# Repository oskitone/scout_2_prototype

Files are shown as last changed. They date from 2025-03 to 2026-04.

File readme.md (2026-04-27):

# scout_2_prototype

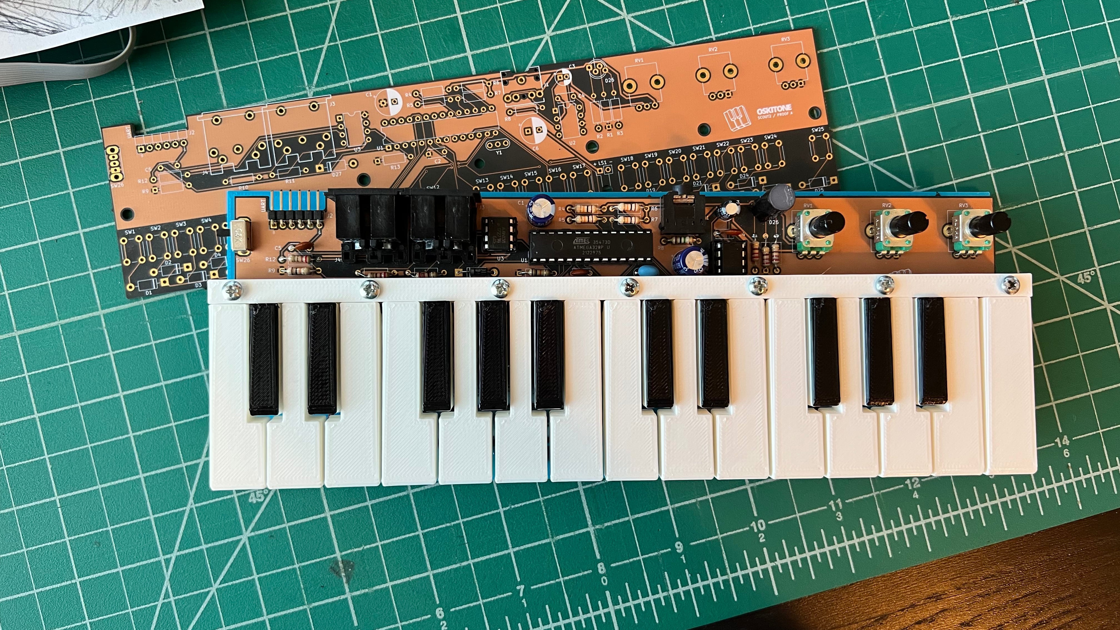
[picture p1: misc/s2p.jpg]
scout_2_prototype


This is a prototype around a PCB I sent off to fab in March 2022... that I'm slowly bringing back to life. I'm kind of using it as a springboard for the next thing, whatever that is and whenever it happens!

Very much work-in-progress. License will be MIT like other kits.

Forked from scout's [2-25_keys](https://github.com/oskitone/scout/tree/2-25_keys) branch

## In this repo

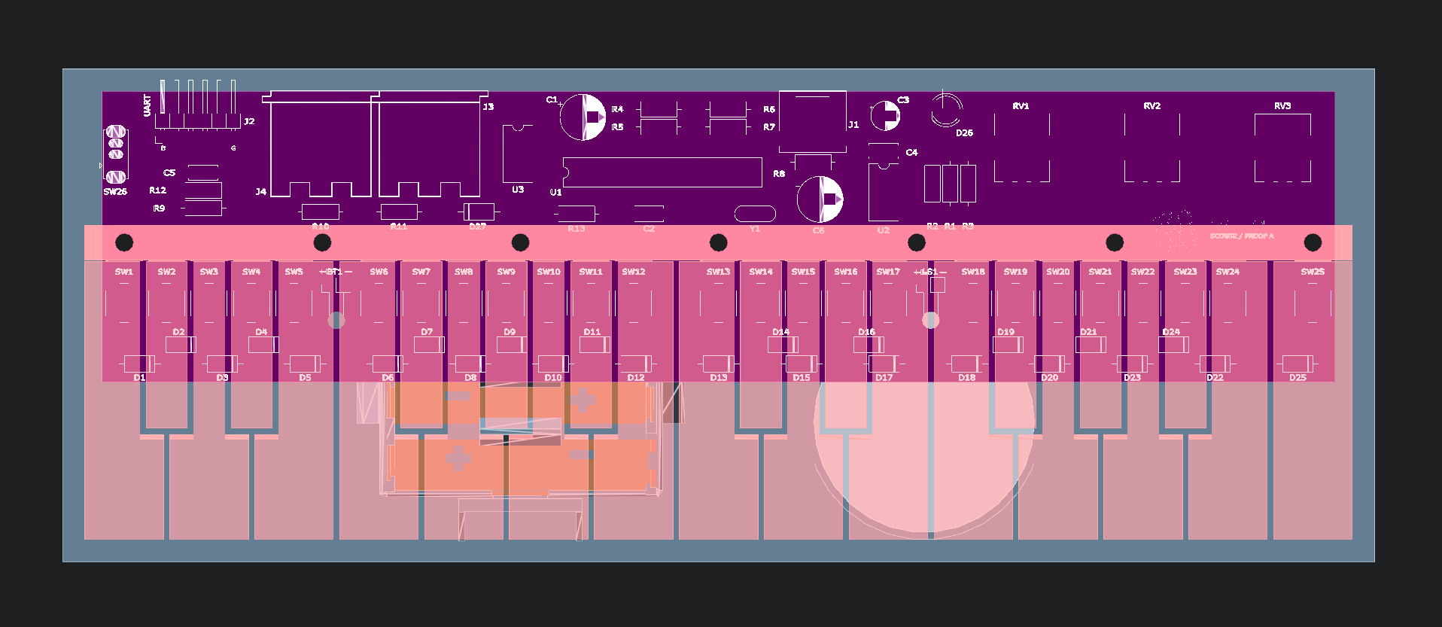
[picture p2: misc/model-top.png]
top view


- Kicad project
- OpenSCAD for scaffolding and keys models
- STLs for 3D-printing

## Goals

### Overarching Oskitone design goals

- Easy to solder. Only through-hole parts, even if it limits functionality.
- Easy to change. Code can be edited with free software and cheap hardware.
- Easy to play. No hidden menus, secret key combos, or overloading. One control per one function.
- Easy to understand. Code should be relatively accessible to anybody familiar with Arduino.
- Easy to hack. Programming header (TODO? hmm), usual open source ethos stuff.

### And specific to the next ~synth

- Polyphony
  - Per my ability, four is a reasonable number of notes to play simultaneously. Three is okay but would be frustrating. Two would be funny?
  - Anyway, four notes is what D9-12 are attempting. At the time, I was thinking I could tack some math around millis() and make the square waves manually... maybe use an interrupt timer? My pin choice seems random, and there're probably better choices.
- Any kind of musical connectivity
  - MIDI
    - USB is modern but circular DIN connectors are standard and inarguably answer the question "But can it do MIDI?!"
    - I think I'd also need non-DIP chips to do USB MIDI so that's out
    - I don't know if both IN and OUT are necessary or which to prefer if there can only be one. DIN connectors are big; [TRS MIDI](https://minimidi.world/) is an option.
  - Control Voltage
    - I'm open to this but don't really know the scene well enough to know what would be good. If it's easy to add, sure.
- Support for Mozzi w/o shipping w/ it
  - I want it to still feel solidly like an Oskitone instrument, for better and no doubt worse. Blame ["not invented here" syndrome](https://en.wikipedia.org/wiki/Not_invented_here).
  - Mozzi is cool as hell but it does require reading docs, which maybe breaks the "easy to understand" goal.
  - <del>Plus, even if I wanted to, I don't think Mozzi's license would permit me selling kits w/ it.</del> [Looks like they're GNU LGPL now](https://github.com/sensorium/Mozzi/pull/240), so may be okay.
  - That having been said, I want to engender "side-loading" things like this and make swapping to Mozzi straightforward, especially if the barrier to entry is low. So minimally it needs the right pins, an output filter, maybe other changes too.
- More musically useful than the Scout
  - Same size keys but as many as I can fit on a Prusa.
  - A semblance of control with analog input pots. Currently doing octave and glide.
  - Glide is fun but will be weird if/when polyphony is introduced. Could do poly only at 0 glide

## TODO / known issues / things for next rev

- 3D prints
  - Octave control really needs detents or some kinda tactile feedback on rotation.
- For next rev
  - More key mounting screw holes? Key bed subassembly with multiple parts
  - Rethink headphone output in signal path to minimize amplified noise
  - 386 bass boost?
  - Fix PROOF silkscreen text on back
  - Try shift register for 8 outputs? To resistor array!
  - Ditch MIDI in. Keep MIDI out but use TRS for smaller footprint
  - See if speaker can fit in new space?
- Tiny speaker is quick to distort and has no low end
- Make it clear/explicit how FUNCTION_INDICATOR_LED is used as "hanging" indicator. Right now, it's incidental.

Anything else?

https://github.com/user-attachments/assets/99f4f9d2-c58f-4821-b225-9032d2b2e849

## Uploading new code

The UART header [works the same as the OG Scout](https://oskitone.github.io/scout/change-the-arduino-code).

The cable's black wire should be on the left and green on the right.

## BOM

| Designator | Footprint | Quantity | Designation |
| --- | --- | --- | --- |
| SW1-SW25 | SW_PUSH_6mm | 25 | SPST |
| BT1 | PinHeader_1x02_P2.54mm_Vertical | 1 | 4.5v |
| LS1 | PinHeader_1x02_P2.54mm_Vertical | 1 | Speaker |
| RV1 | Potentiometer_Bourns_PTV09A-1_Single_Vertical | 1 | 10k Log |
| Y1 | Resonator-3Pin_W7.0mm_H2.5mm | 1 | 16.00MHz |
| U2 | DIP-8_W7.62mm | 1 | LM386 |
| R4,R5,R7,R6 | R_Axial_DIN0207_L6.3mm_D2.5mm_P10.16mm_Horizontal | 4 | 10K |
| J1 | AUDIO-JACK | 1 | AudioJack2_SwitchT |
| C2,C4,C5 | C_Disc_D5.0mm_W2.5mm_P5.00mm | 3 | .1uF |
| C6,C1 | CP_Radial_D8.0mm_P3.50mm | 2 | 220uF |
| U1 | DIP-28_W7.62mm | 1 | ATmega328P-PU |
| D1-D25,D27 | D_DO-41_SOD81_P10.16mm_Horizontal | 26 | D |
| J2 | PinHeader_1x06_P2.54mm_Horizontal | 1 | Conn_01x06_Male |
| R8 | R_Axial_DIN0207_L6.3mm_D2.5mm_P10.16mm_Horizontal | 1 | 1m |
| R9,R13 | R_Axial_DIN0207_L6.3mm_D2.5mm_P10.16mm_Horizontal | 2 | 10k |
| R10,R1,R11,R3,R2,R12 | R_Axial_DIN0207_L6.3mm_D2.5mm_P10.16mm_Horizontal | 6 | 220 |
| D26 | LED_D5.0mm-4_RGB_Staggered_Pins | 1 | LED_CRGB |
| J4,J3 | DIN5-RA-PTH | 2 | DIN5 |
| SW26 | SW_Slide_1P2T_CK_OS102011MS2Q | 1 | SW_SPST |
| RV2,RV3 | Potentiometer_Bourns_PTV09A-1_Single_Vertical | 2 | 10k |
| C3 | CP_Radial_D5.0mm_P2.00mm | 1 | 1uF |
| U3 | DIP-8_W7.62mm | 1 | 6N138 |

## Schematics

TODO: update to PROOF B

scout_2_prototype-schematic

scout_2_prototype-keyboard_matrix-schematic

## 3D Models

Normally I'd put them on thingiverse/etc, but here they're included in the repo in the `stls` folder.

### OpenSCAD dependencies

Assumes `parts_cafe` is in a sibling directory and is up to date on the `main` branch. Here's how I've got it:

    \ oskitone
        \ parts_cafe
        \ scout_2_prototype

You'll also need to install the [Orbitron](https://fonts.google.com/specimen/Orbitron) font.

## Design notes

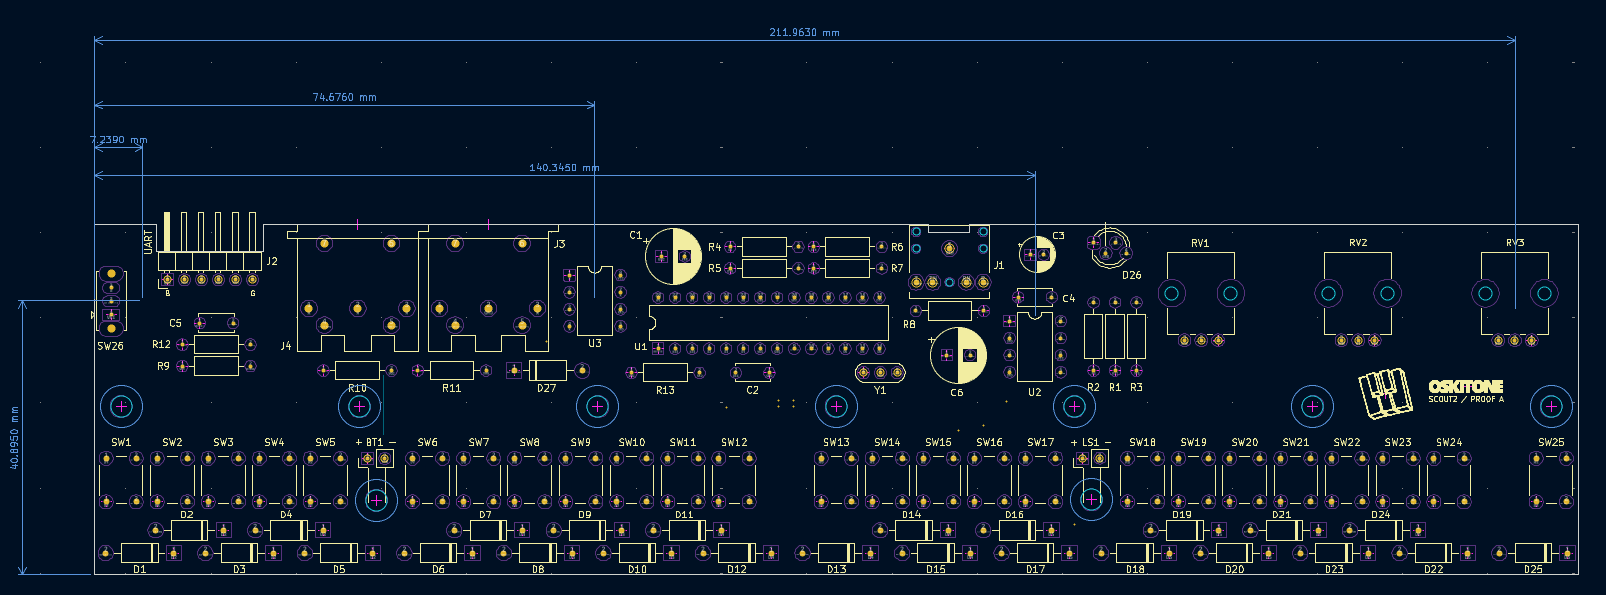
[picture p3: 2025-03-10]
misc/support_positions.png

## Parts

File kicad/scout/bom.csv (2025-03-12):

Id | Designator | Footprint | Quantity | Designation | Supplier and ref
1 | SW4,SW10,SW2,SW3,SW5,SW6,SW7,SW8,SW9,SW11,SW12,SW13,SW14,SW15,SW16,SW17,SW18,SW1,SW24,SW19,SW20,SW22,SW21,SW25,SW23 | SW_PUSH_6mm | 25 | SPST
2 | BT1 | PinHeader_1x02_P2.54mm_Vertical | 1 | 4.5v
3 | LS1 | PinHeader_1x02_P2.54mm_Vertical | 1 | Speaker
4 | RV1 | Potentiometer_Bourns_PTV09A-1_Single_Vertical | 1 | 10k Log
5 | Y1 | Resonator-3Pin_W7.0mm_H2.5mm | 1 | 16.00MHz
6 | U2 | DIP-8_W7.62mm | 1 | LM386
7 | R4,R5,R7,R6 | R_Axial_DIN0207_L6.3mm_D2.5mm_P10.16mm_Horizontal | 4 | 10K
8 | J1 | AUDIO-JACK | 1 | AudioJack2_SwitchT
9 | Ref** | logo | 1 | Val**
10 | C2,C4,C5 | C_Disc_D5.0mm_W2.5mm_P5.00mm | 3 | .1uF
11 | C6,C1 | CP_Radial_D8.0mm_P3.50mm | 2 | 220uF
12 | U1 | DIP-28_W7.62mm | 1 | ATmega328P-PU
13 | D1,D14,D24,D25,D7,D17,D12,D13,D18,D15,D4,D22,D11,D6,D19,D2,D20,D27,D9,D10,D5,D16,D23,D3,D21,D8 | D_DO-41_SOD81_P10.16mm_Horizontal | 26 | D
14 | J2 | PinHeader_1x06_P2.54mm_Horizontal | 1 | Conn_01x06_Male
15 | Ref** | branding | 1 | Val**
16 | R8 | R_Axial_DIN0207_L6.3mm_D2.5mm_P10.16mm_Horizontal | 1 | 1m
17 | R9,R13 | R_Axial_DIN0207_L6.3mm_D2.5mm_P10.16mm_Horizontal | 2 | 10k
18 | R10,R1,R11,R3,R2,R12 | R_Axial_DIN0207_L6.3mm_D2.5mm_P10.16mm_Horizontal | 6 | 220
19 | D26 | LED_D5.0mm-4_RGB_Staggered_Pins | 1 | LED_CRGB
20 | J4,J3 | DIN5-RA-PTH | 2 | DIN5
21 | SW26 | SW_Slide_1P2T_CK_OS102011MS2Q | 1 | SW_SPST
22 | RV2,RV3 | Potentiometer_Bourns_PTV09A-1_Single_Vertical | 2 | 10k
23 | C3 | CP_Radial_D5.0mm_P2.00mm | 1 | 1uF
24 | U3 | DIP-8_W7.62mm | 1 | 6N138

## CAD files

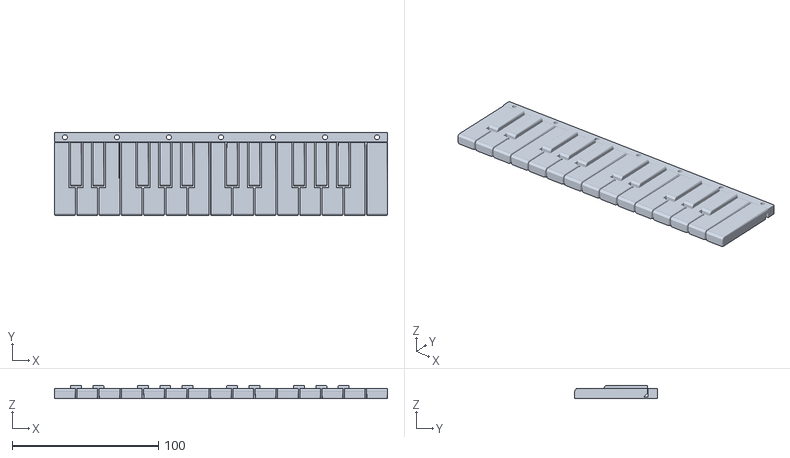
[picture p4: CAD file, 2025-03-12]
stls/s2p-5e9df84-keys.stl
227.6 x 56.6 x 9.00

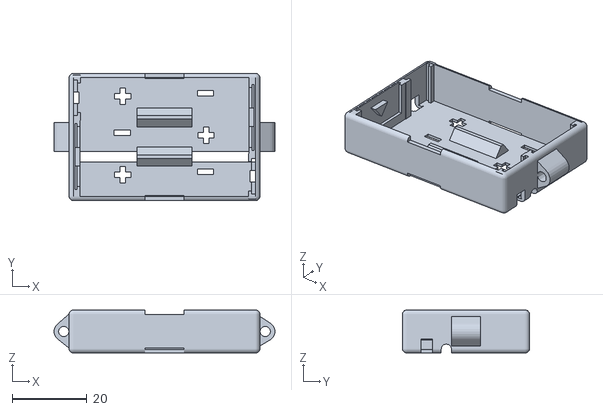
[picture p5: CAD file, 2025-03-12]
stls/s2p-5e9df84-battery_holder.stl
59.1 x 34.1 x 11.5

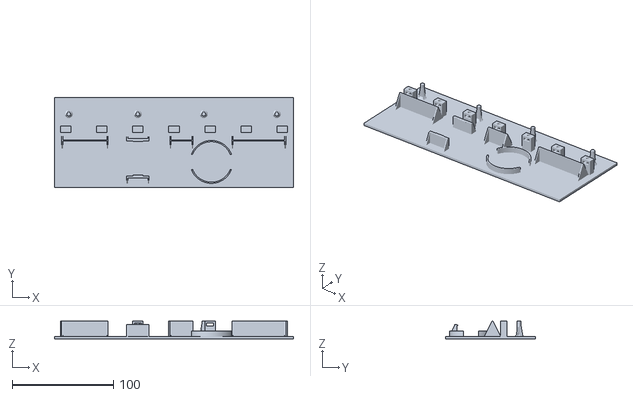
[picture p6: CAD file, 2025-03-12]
stls/s2p-5e9df84-base.stl
235.6 x 88.6 x 17.5

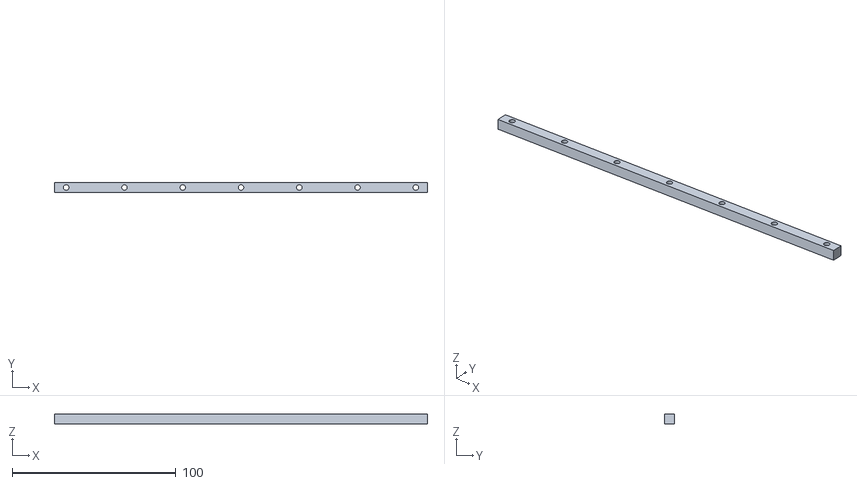
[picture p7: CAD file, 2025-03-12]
stls/s2p-5e9df84-mounting_rail.stl
227.6 x 6.40 x 6.00

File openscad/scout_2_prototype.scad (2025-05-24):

include <../../parts_cafe/openscad/battery_holder.scad>;
include <../../parts_cafe/openscad/battery_holder_fixtures.scad>;
include <../../parts_cafe/openscad/support_bar.scad>;
include <../../parts_cafe/openscad/keys.scad>;
include <../../parts_cafe/openscad/pcb_base.scad>;
include <../../parts_cafe/openscad/pcb.scad>;
include <../../parts_cafe/openscad/speaker-AZ40R.scad>;

module scout_2_prototype(
    kicad_edge_cuts = EXAMPLE_EDGE_CUTS,
    kicad_screw_positions = [[0,0]],
    kicad_wire_relief_positions = [[0,0]],

    fillet_keys = true,
    keys_length = SCOUT_NATURAL_KEY_LENGTH,

    pcb_silkscreen_path = "../kicad/XYZ-brd.svg",
    pcb_bottom_clearance = 15,

    padding = 4,
    tolerance = .1,

    battery_holder_web_length = BATTERY_HOLDER_FIXTURE_HITCH_WEB_LENGTH / 2,

    show_base = true,
    show_battery_holder = true,
    show_speaker = true,
    show_pcb = true,
    show_pcb_silkscreen = true,
    show_mounting_rail = true,
    show_keys = true,

    quick_preview = $preview
) {
    e = .041;

    keys_total_width = get_keys_total_width(25);
    keys_total_length = get_mounted_keys_total_length(tolerance);

    base_width = keys_total_width + padding * 2;

    pcb_dimensions = get_pcb_dimensions(kicad_edge_cuts);
    pcb_component_offset_position = get_pcb_component_offset_position(kicad_edge_cuts);
    screw_positions = get_pcb_component_positions(
        kicad_screw_positions, pcb_component_offset_position, pcb_dimensions);
    wire_relief_positions = get_pcb_component_positions(
        kicad_wire_relief_positions, pcb_component_offset_position, pcb_dimensions);

    battery_holder_dimensions = get_battery_holder_dimensions(
        count = 3,
        tolerance = tolerance
    );

    pcb_position = [
        (base_width - pcb_dimensions.x) / 2,
        keys_total_length
            - screw_positions[0].y - KEYS_MOUNT_LENGTH / 2
            + padding,
        get_pcb_base_total_height(
            min_clearance = pcb_bottom_clearance,
            pcb_mount_post_ceiling = PCB_MOUNT_POST_CEILING
        )
    ];

    base_length = pcb_position.y + pcb_dimensions.y + padding;

    keys_position = [
        (base_width - keys_total_width) / 2,
        pcb_position.y
            + screw_positions[0].y + KEYS_MOUNT_LENGTH / 2
            - keys_total_length,
        pcb_position.z + PCB_HEIGHT + SPST_ACTUATOR_HEIGHT_OFF_PCB
    ];

    // NOTE: eyeballed!
    battery_holder_position = [80, 4, PCB_BASE_BASE_HEIGHT];

    echo(str("battery_holder_dimensions = ", battery_holder_dimensions));

    speaker_fixture_diameter = get_speaker_fixture_diameter(tolerance);
    speaker_position = [
        pcb_position.x + pcb_dimensions.x * (2/3),
        speaker_fixture_diameter / 2 + padding,
        PCB_BASE_BASE_HEIGHT - e
    ];

    module _base(
        support_bar_pcb_xs = [0, SPST_PLOT * 10, SPST_PLOT * 22],
        support_bar_pcb_y = 14,
        support_bar_widths = [SPST_PLOT * 5, SPST_PLOT * 7, SPST_PLOT * 7],

        // Eyeballed! See images/support_positions.png
        stool_pcb_positions = [
            [7, 40],
            [75, 40],
            [140, 40],
            [212, 40],
        ]
    ) {
        z = PCB_BASE_BASE_HEIGHT - e;

        pcb_base(
            width = base_width,
            length = base_length,
            pcb_bottom_clearance = pcb_bottom_clearance,
            screw_positions = [ for (xy = screw_positions) [
                xy.x + pcb_position.x,
                xy.y + pcb_position.y
            ] ],
            stool_positions = [
                for (xy = stool_pcb_positions) [
                    xy.x + pcb_position.x,
                    xy.y + pcb_position.y
                ]
            ],
            tolerance = tolerance,
            show_dfm = !$preview
        );

        translate([
            battery_holder_position.x + (BATTERY_HOLDER_DEFAULT_WALL + tolerance),
            battery_holder_position.y - (BATTERY_HOLDER_DEFAULT_WALL + tolerance),
            battery_holder_position.z - e
        ]) rotate([0, 0, 90]) {
            battery_holder_hitches(
                tolerance = tolerance,
                battery_holder_dimensions = battery_holder_dimensions,
                web_length = battery_holder_web_length
            );
        }

        translate(speaker_position) {
            speaker_fixture(
                tab_cavity_count = 2,
                tab_cavity_rotation = 90,
                tolerance = tolerance,
                quick_preview = quick_preview
            );
        }

        for (i = [0 : len(support_bar_pcb_xs) - 1]) {
            x = support_bar_pcb_xs[i];
            width = support_bar_widths[i];
            height = pcb_position.z - PCB_BASE_BASE_HEIGHT;

            translate([
                pcb_position.x + x,
                pcb_position.y + support_bar_pcb_y - SUPPORT_BAR_LENGTH / 2,
                PCB_BASE_BASE_HEIGHT - e
            ]) {
                render() support_bar(
                    width = width,
                    height = height + e,
                    web_chamfer = height / 2
                );
            }
        }
    }

    module _keys(mounting_rail = false) {
        keys(
            count = 25,
            natural_length = keys_length,
            mount_height = mounting_rail
                ? SPST_ACTUATOR_HEIGHT_OFF_PCB
                : SCOUT_NATURAL_KEY_HEIGHT,
            mount_hole_xs = [ for (xy = screw_positions)
                xy.x + keys_position.x - KEY_GUTTER + tolerance
            ],
            front_fillet = fillet_keys ? KEY_FRONT_FILLET : 0,
            sides_fillet = fillet_keys ? KEY_SIDES_FILLET : 0,
            tolerance = tolerance,
            include_mount = true,
            include_natural = !mounting_rail,
            include_accidental = !mounting_rail,
            include_cantilevers = !mounting_rail,
            quick_preview = quick_preview
        );
    }

    if (show_base) {
        _base();
    }

    if (show_battery_holder) {
        translate([0,0,BATTERY_HOLDER_DEFAULT_FLOOR -e]) translate(battery_holder_position) {
            rotate([0, 0, 90]) battery_holder(
                tolerance = tolerance,
                quick_preview = quick_preview
            );
        }
    }

    if (show_speaker) {
        translate(speaker_position) {
            % speaker();
        }
    }

    if (show_pcb) {
        translate(pcb_position) {
            pcb(
                width = pcb_dimensions.x,
                length = pcb_dimensions.y,
                hole_positions =
                    cat(wire_relief_positions, screw_positions),
                show_silkscreen = show_pcb_silkscreen,
                silkscreen_path = pcb_silkscreen_path
            );
        }
    }

    if (show_mounting_rail) {
        translate([
            keys_position.x,
            keys_position.y,
            pcb_position.z + PCB_HEIGHT
        ]) _keys(mounting_rail = true);
    }

    if (show_keys) {
        translate(keys_position) _keys();
    }

}

scout_2_prototype(
    kicad_edge_cuts = [
        [[58.628586, 62.273], [157.861, 62.273]],
        [[42.626586, 62.273], [33.355586, 62.273]],
        [[58.628586, 66.337], [58.628586, 62.273]],
        [[163.957, 62.273], [254.771586, 62.273]],
        [[42.626586, 62.273], [42.626586, 66.337]],
        [[33.355586, 114.555], [33.355586, 62.273]],
        [[163.957, 63.4238], [163.957, 62.273]],
        [[33.355586, 114.555], [254.771586, 114.555]],
        [[157.861, 63.4238], [163.957, 63.4238]],
        [[42.626586, 66.337], [58.628586, 66.337]],
        [[254.771586, 114.555], [254.771586, 62.273]],
        [[157.861, 62.273], [157.861, 63.4238]],
    ],
    kicad_screw_positions = [
        [108.503586, 89.451],
        [72.943586, 89.451],
        [215.183586, 89.451],
        [144.063586, 89.451],
        [179.623586, 89.451],
        [250.743586, 89.451],
        [37.383586, 89.451],
    ],
    kicad_wire_relief_positions = [
        [182.16, 103.375],
        [75.46329, 103.425],
    ],
    fillet_keys = !$preview,
    pcb_silkscreen_path = "../misc/scout-2-brd-d72051a.svg",
    show_base = true,
    show_battery_holder = true,
    show_speaker = true,
    show_pcb = true,
    show_pcb_silkscreen = false,
    show_mounting_rail = true,
    show_keys = true
);

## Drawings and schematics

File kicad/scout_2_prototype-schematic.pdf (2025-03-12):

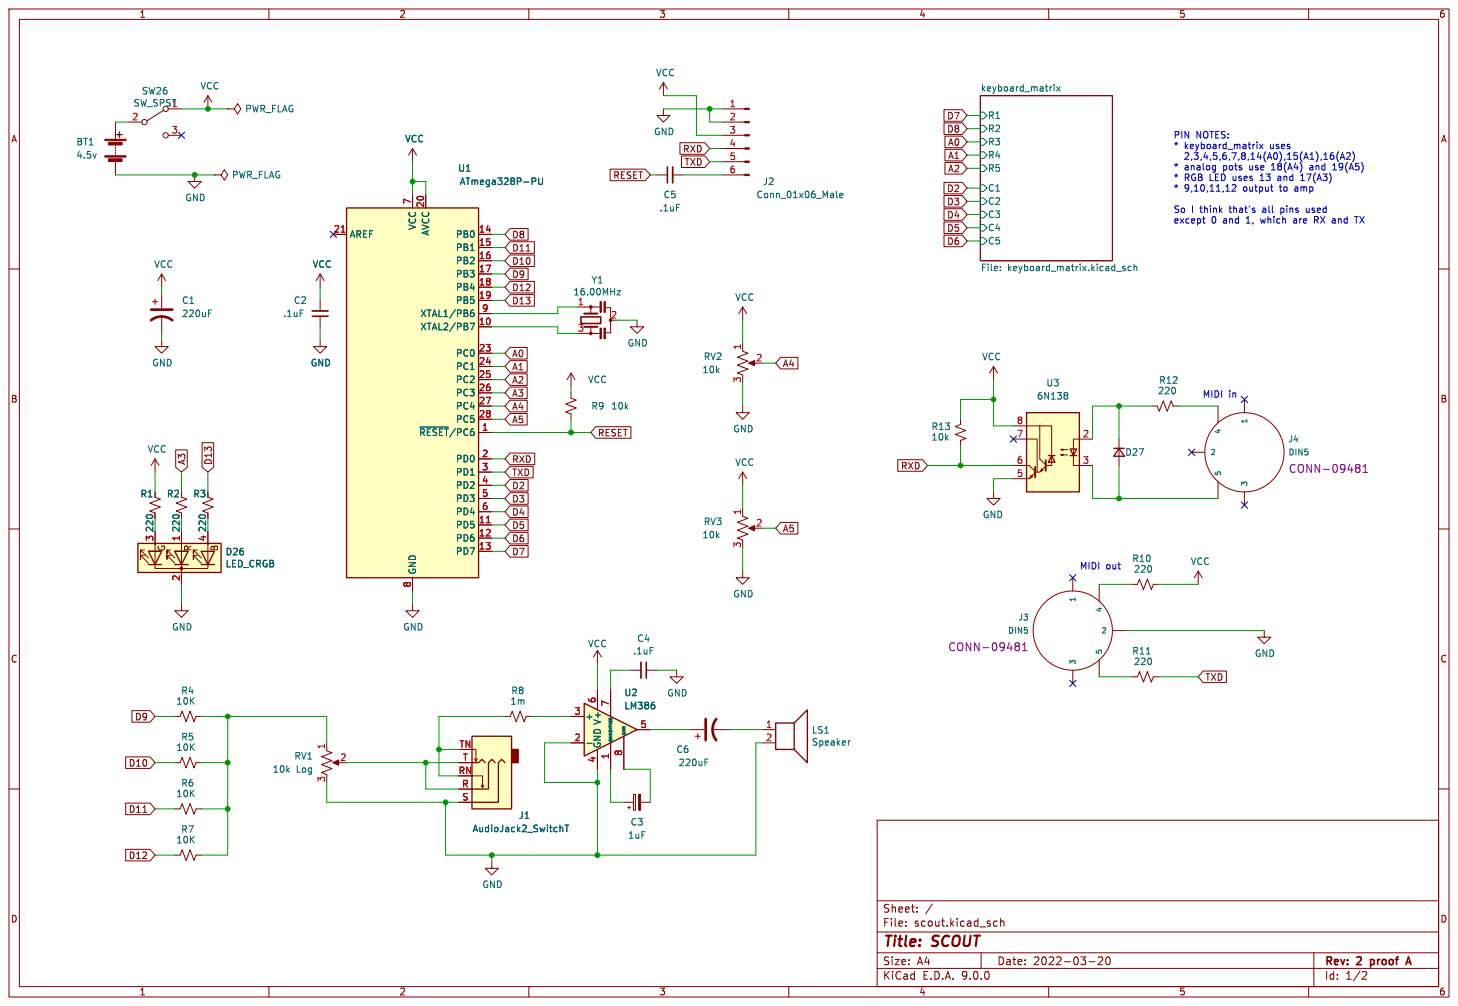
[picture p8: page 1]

except 0 and 1, which are RX and TX U2

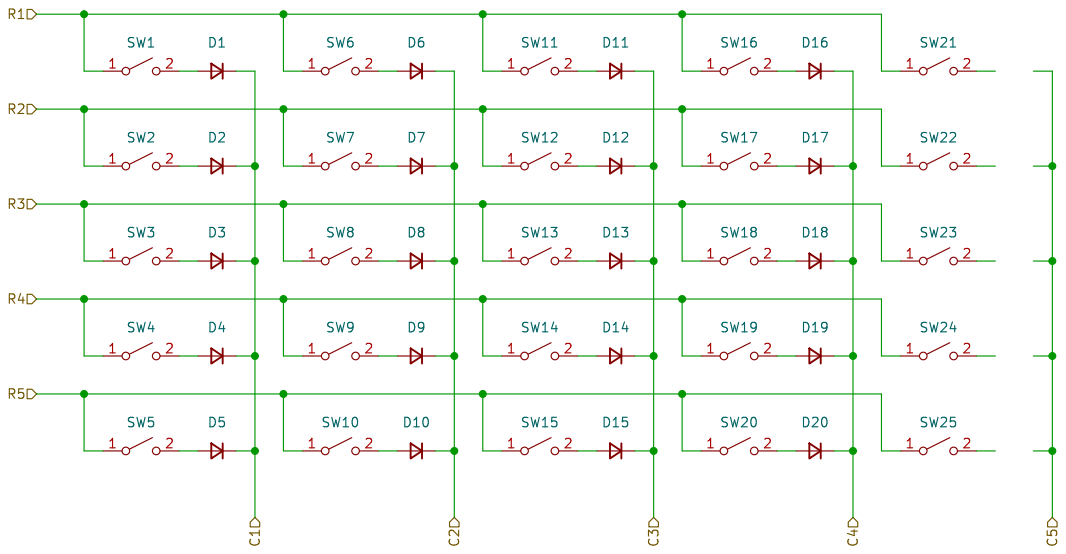
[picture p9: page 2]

Id: 2/2 Title: File: keyboard_matrix.kicad_sch Sheet: /keyboard_matrix/

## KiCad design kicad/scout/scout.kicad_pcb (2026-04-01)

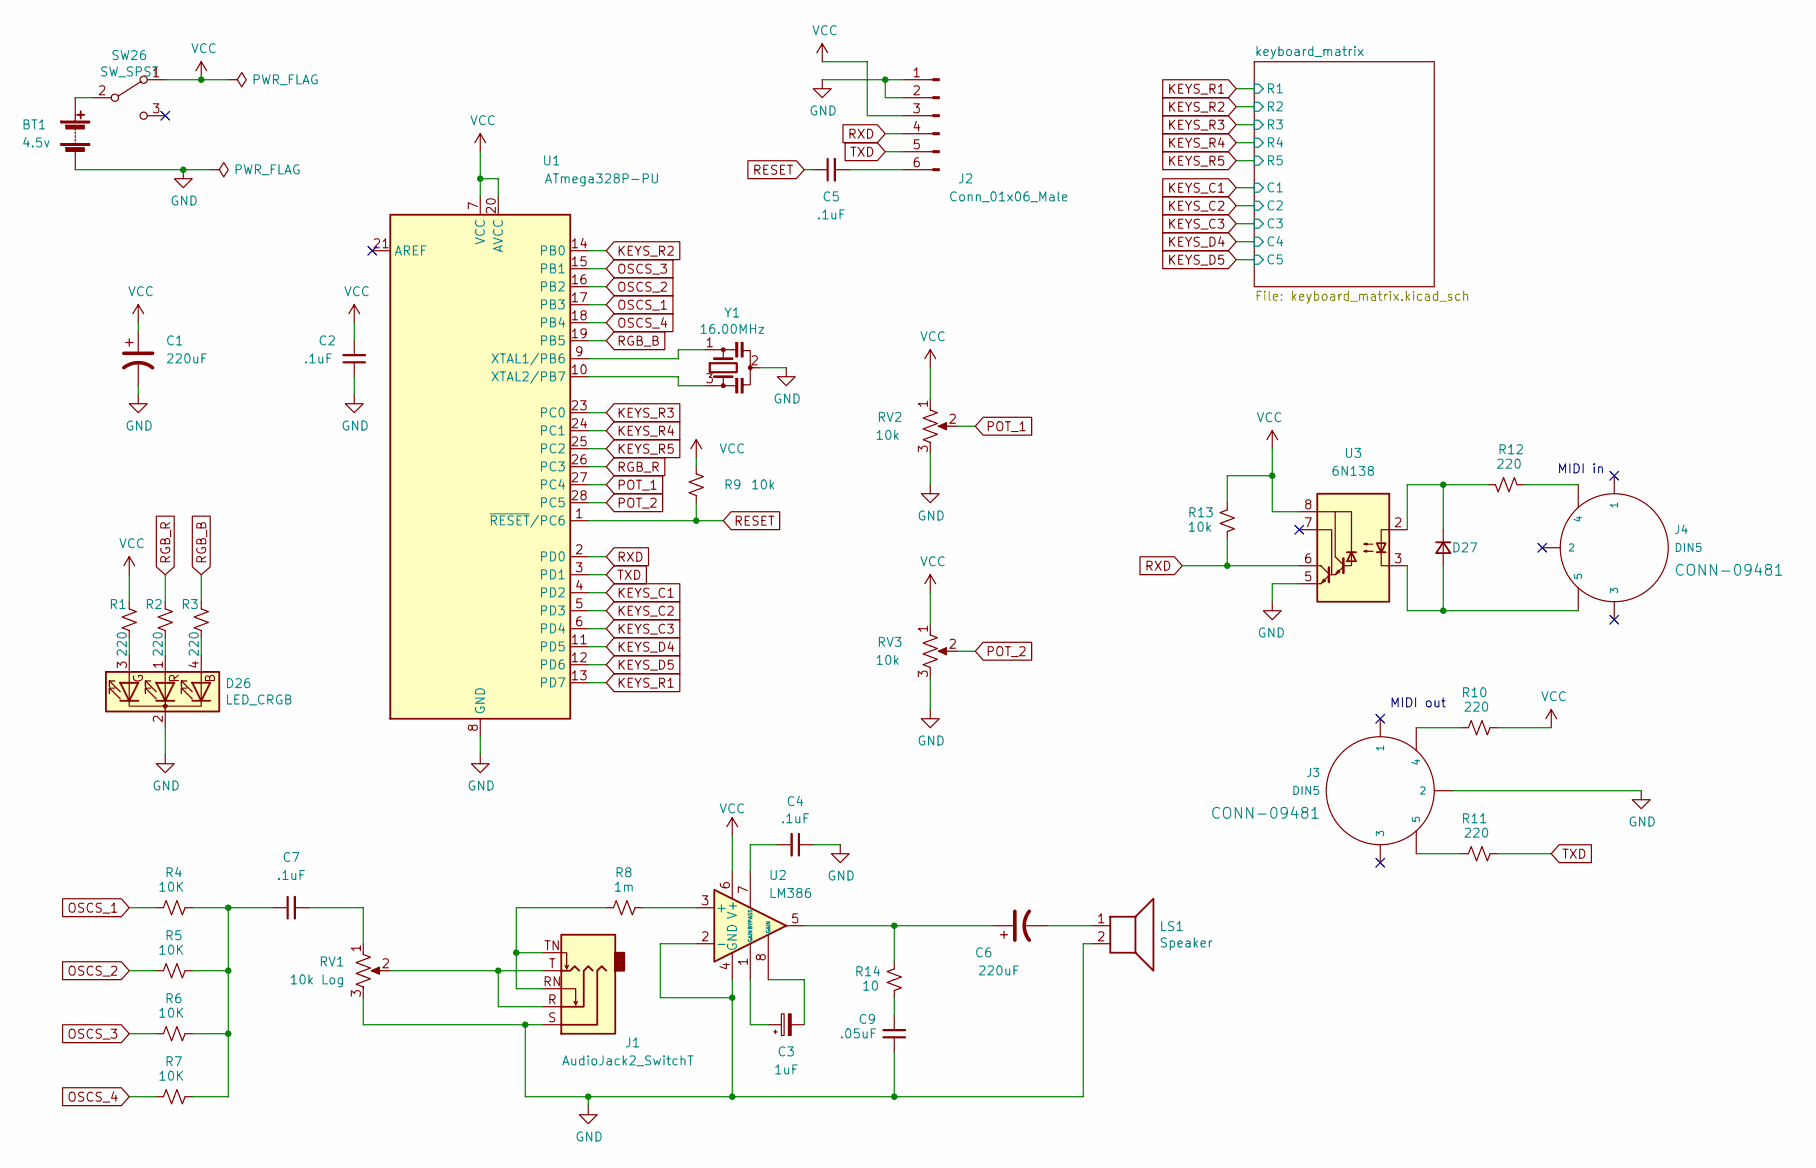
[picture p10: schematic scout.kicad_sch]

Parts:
BT1: 4.5v; PinHeader_1x02_P2.54mm_Vertical
C1, C6: 220uF; CP_Radial_D8.0mm_P3.50mm
C2, C4, C5, C7: .1uF; C_Disc_D5.0mm_W2.5mm_P5.00mm
C3: 1uF; CP_Radial_D5.0mm_P2.00mm
C9: .05uF; C_Disc_D5.0mm_W2.5mm_P5.00mm
D26: LED_CRGB; LED_D5.0mm-4_RGB_Staggered_Pins
D27: D; D_DO-41_SOD81_P10.16mm_Horizontal
J1: AudioJack2_SwitchT; AUDIO-JACK
J2: Conn_01x06_Male; PinHeader_1x06_P2.54mm_Horizontal
J3, J4: DIN5; DIN5-RA-PTH
LS1: Speaker; PinHeader_1x02_P2.54mm_Vertical
R1, R2, R3, R10, R11, R12: 220; R_Axial_DIN0207_L6.3mm_D2.5mm_P10.16mm_Horizontal
R4, R5, R6, R7: 10K; R_Axial_DIN0207_L6.3mm_D2.5mm_P10.16mm_Horizontal
R8: 1m; R_Axial_DIN0207_L6.3mm_D2.5mm_P10.16mm_Horizontal
R9, R13: 10k; R_Axial_DIN0207_L6.3mm_D2.5mm_P10.16mm_Horizontal
R14: 10; R_Axial_DIN0207_L6.3mm_D2.5mm_P10.16mm_Horizontal
RV1: 10k Log; Potentiometer_Bourns_PTV09A-1_Single_Vertical
RV2, RV3: 10k; Potentiometer_Bourns_PTV09A-1_Single_Vertical
SW26: SW_SPST; SW_Slide_1P2T_CK_OS102011MS2Q
U1: ATmega328P-PU; DIP-28_W7.62mm
U2: LM386; DIP-8_W7.62mm
U3: 6N138; DIP-8_W7.62mm
Y1: 16.00MHz; Resonator-3Pin_W7.0mm_H2.5mm

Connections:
GND: BT1.2 (-), C1.2, C2.1, C4.1, C9.1, D26.2 (K), J1.S, J2.1, J2.2, J3.2, LS1.2, RV1.3, RV2.3, RV3.3, U1.8 (GND), U1.22 (GND), U2.2 (-), U2.4 (GND), U3.5 (GND), Y1.2
KEYS_C1: U1.4 (PD2); also elsewhere on the board
KEYS_C2: U1.5 (PD3); also elsewhere on the board
KEYS_C3: U1.6 (PD4); also elsewhere on the board
KEYS_D4: U1.11 (PD5); also elsewhere on the board
KEYS_D5: U1.12 (PD6); also elsewhere on the board
KEYS_R1: U1.13 (PD7); also elsewhere on the board
KEYS_R2: U1.14 (PB0); also elsewhere on the board
KEYS_R3: U1.23 (PC0); also elsewhere on the board
KEYS_R4: U1.24 (PC1); also elsewhere on the board
KEYS_R5: U1.25 (PC2); also elsewhere on the board
unnamed: BT1.1 (+), SW26.2 (B)
unnamed: C3.1, U2.1 (GAIN)
unnamed: C3.2, U2.8 (GAIN)
unnamed: C6.1, R14.1, U2.5
unnamed: C6.2, LS1.1
unnamed: C7.1, R4.2, R5.2, R6.2, R7.2
unnamed: C7.2, RV1.1
unnamed: C9.2, R14.2
unnamed: D26.4 (BA), R3.2
unnamed: D26.1 (GA), R2.2
unnamed: D26.3 (RA), R1.2
unnamed: D27.2 (A), J4.5, U3.3 (C2)
unnamed: D27.1 (K), R12.2, U3.2 (C1)
unnamed: J1.R, J1.T, RV1.2
unnamed: J1.RN, J1.TN, R8.1
unnamed: C5.2, J2.6
unnamed: J3.4, R10.1
unnamed: J3.5, R11.1
unnamed: J4.4, R12.1
unnamed: U1.9 (XTAL1/PB6), Y1.1
unnamed: U1.10 (XTAL2/PB7), Y1.3
unnamed: R8.2, U2.3 (+)
unnamed: C4.2, U2.7 (BYPASS)
OSCS_1: R4.1, U1.17 (PB3)
OSCS_2: R5.1, U1.16 (PB2)
OSCS_3: R6.1, U1.15 (PB1)
OSCS_4: R7.1, U1.18 (PB4)
POT_1: RV2.2, U1.27 (PC4)
POT_2: RV3.2, U1.28 (PC5)
RESET: C5.1, R9.2, U1.1 (~RESET/PC6)
RGB_B: R3.1, U1.19 (PB5)
RGB_R: R2.1, U1.26 (PC3)
RXD: J2.4, R13.2, U1.2 (PD0), U3.6 (VO2)
TXD: J2.5, R11.2, U1.3 (PD1)
VCC: C1.1, C2.2, J2.3, R1.1, R9.1, R10.2, R13.1, RV2.1, RV3.1, SW26.1 (A), U1.7 (VCC), U1.20 (AVCC), U2.6 (V+), U3.8 (VCC)

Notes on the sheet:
MIDI in
MIDI out

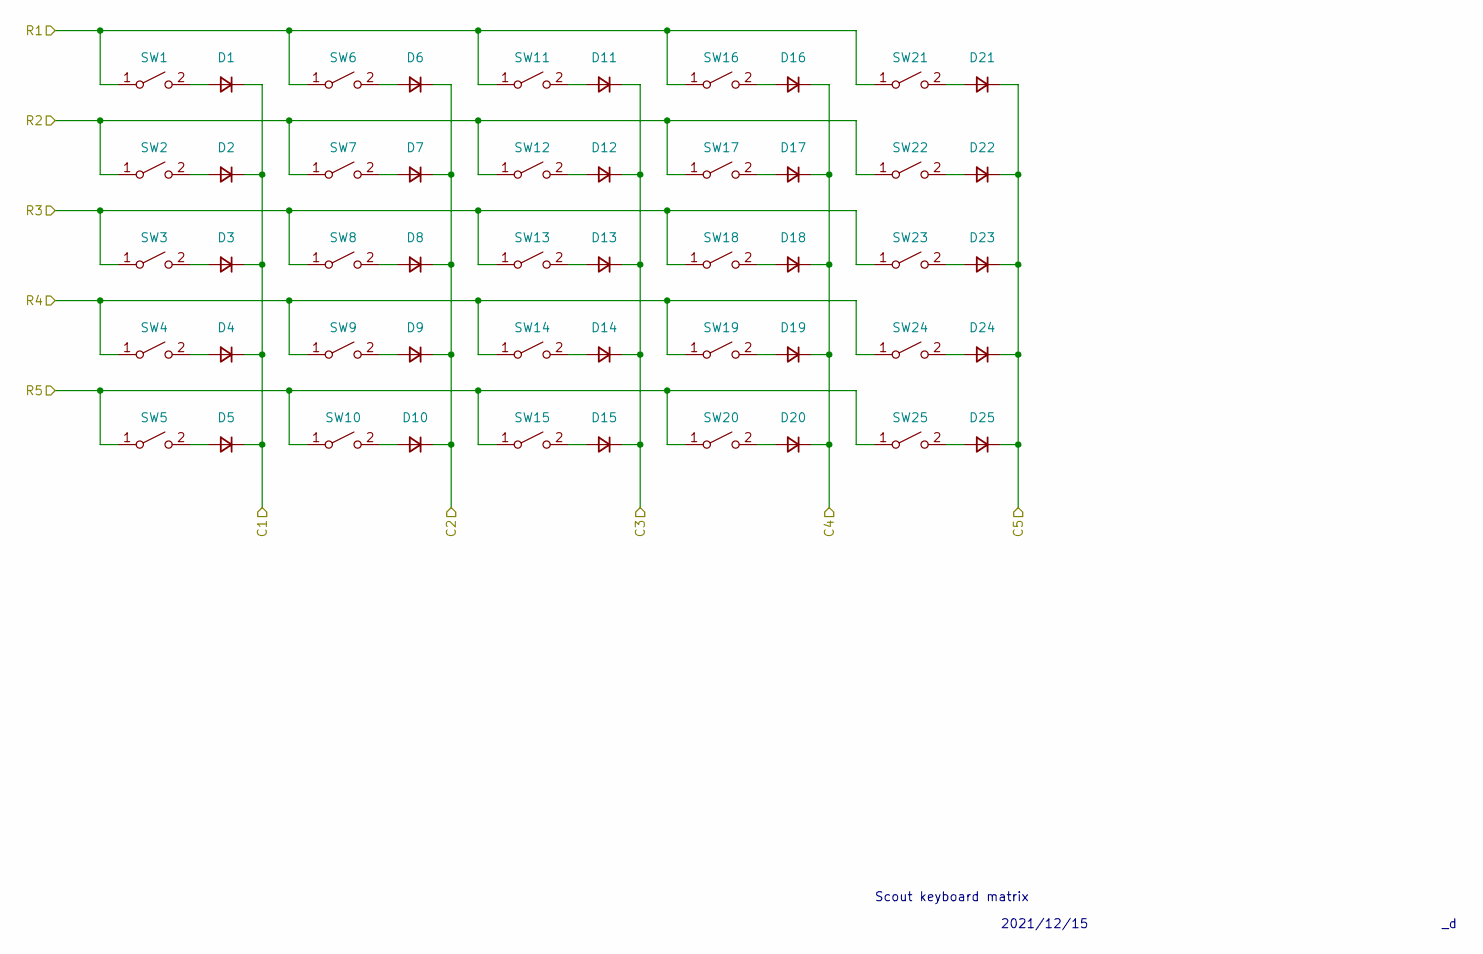
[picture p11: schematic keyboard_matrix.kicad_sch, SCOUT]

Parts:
D1, D2, D3, D4, D5, D6, D7, D8, D9, D10, D11, D12, D13, D14, D15, D16, D17, D18, D19, D20, D21, D22, D23, D24, D25: 1N4148; D_DO-41_SOD81_P10.16mm_Horizontal
SW1, SW2, SW3, SW4, SW5, SW6, SW7, SW8, SW9, SW10, SW11, SW12, SW13, SW14, SW15, SW16, SW17, SW18, SW19, SW20, SW21, SW22, SW23, SW24, SW25: SPST; SW_PUSH_6mm

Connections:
KEYS_C1: D1.1 (K), D2.1 (K), D3.1 (K), D4.1 (K), D5.1 (K); also elsewhere on the board
KEYS_C2: D6.1 (K), D7.1 (K), D8.1 (K), D9.1 (K), D10.1 (K); also elsewhere on the board
KEYS_C3: D11.1 (K), D12.1 (K), D13.1 (K), D14.1 (K), D15.1 (K); also elsewhere on the board
KEYS_D4: D16.1 (K), D17.1 (K), D18.1 (K), D19.1 (K), D20.1 (K); also elsewhere on the board
KEYS_D5: D21.1 (K), D22.1 (K), D23.1 (K), D24.1 (K), D25.1 (K); also elsewhere on the board
KEYS_R1: SW1.1 (A), SW6.1 (A), SW11.1 (A), SW16.1 (A), SW21.1 (A); also elsewhere on the board
KEYS_R2: SW2.1 (A), SW7.1 (A), SW12.1 (A), SW17.1 (A), SW22.1 (A); also elsewhere on the board
KEYS_R3: SW3.1 (A), SW8.1 (A), SW13.1 (A), SW18.1 (A), SW23.1 (A); also elsewhere on the board
KEYS_R4: SW4.1 (A), SW9.1 (A), SW14.1 (A), SW19.1 (A), SW24.1 (A); also elsewhere on the board
KEYS_R5: SW5.1 (A), SW10.1 (A), SW15.1 (A), SW20.1 (A), SW25.1 (A); also elsewhere on the board
unnamed: D1.2 (A), SW1.2 (B)
unnamed: D2.2 (A), SW2.2 (B)
unnamed: D3.2 (A), SW3.2 (B)
unnamed: D4.2 (A), SW4.2 (B)
unnamed: D5.2 (A), SW5.2 (B)
unnamed: D6.2 (A), SW6.2 (B)
unnamed: D7.2 (A), SW7.2 (B)
unnamed: D8.2 (A), SW8.2 (B)
unnamed: D9.2 (A), SW9.2 (B)
unnamed: D10.2 (A), SW10.2 (B)
unnamed: D11.2 (A), SW11.2 (B)
unnamed: D12.2 (A), SW12.2 (B)
unnamed: D13.2 (A), SW13.2 (B)
unnamed: D14.2 (A), SW14.2 (B)
unnamed: D15.2 (A), SW15.2 (B)
unnamed: D16.2 (A), SW16.2 (B)
unnamed: D17.2 (A), SW17.2 (B)
unnamed: D18.2 (A), SW18.2 (B)
unnamed: D19.2 (A), SW19.2 (B)
unnamed: D20.2 (A), SW20.2 (B)
unnamed: D21.2 (A), SW21.2 (B)
unnamed: D22.2 (A), SW22.2 (B)
unnamed: D23.2 (A), SW23.2 (B)
unnamed: D24.2 (A), SW24.2 (B)
unnamed: D25.2 (A), SW25.2 (B)

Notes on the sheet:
2021/12/15
Scout keyboard matrix

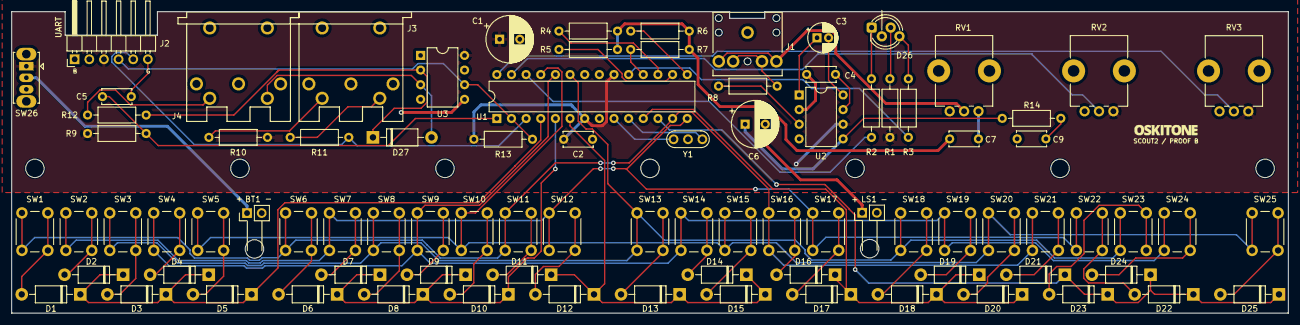
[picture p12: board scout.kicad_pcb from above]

Board: 2 copper layers, 221.4 x 52.3 mm, 98 parts (0 on the bottom side), 71 nets.

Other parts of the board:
 : MountingHole_3.2mm_M3
 #2,  #3,  #4,  #5,  #6,  #7,  #8,  #9: MountingHole_3.2mm_M3
Ref**: Val**; branding

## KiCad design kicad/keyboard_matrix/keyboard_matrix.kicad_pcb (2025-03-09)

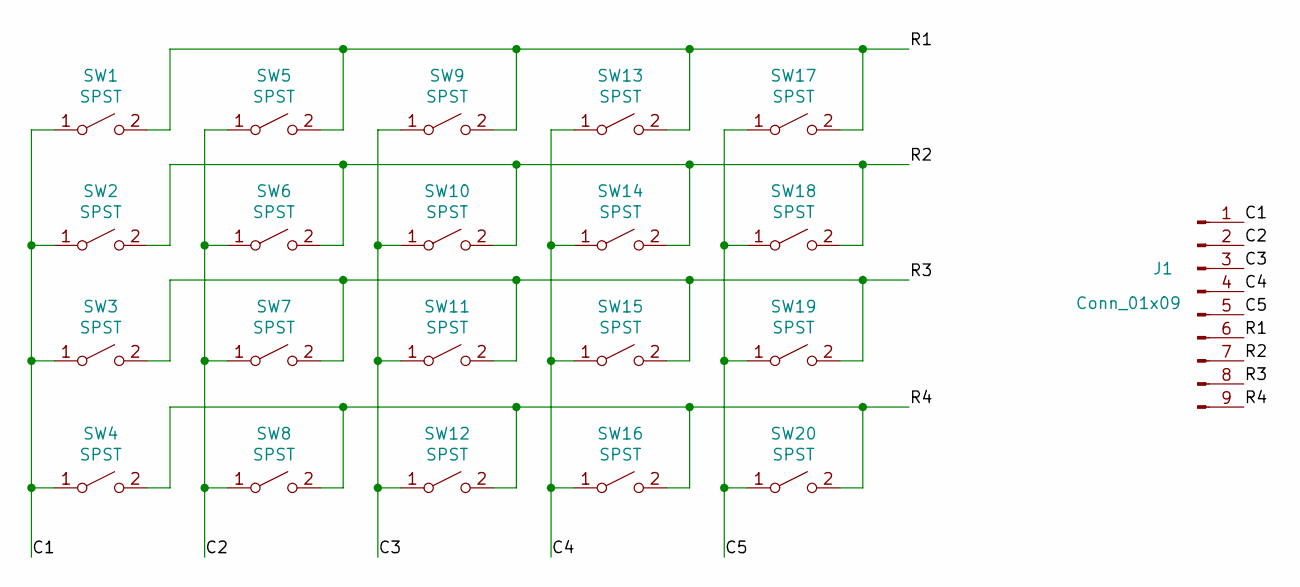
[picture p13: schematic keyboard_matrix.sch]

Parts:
J1: Conn_01x09; PinHeader_1x09_P2.54mm_Horizontal
SW1, SW2, SW3, SW4, SW5, SW6, SW7, SW8, SW9, SW10, SW11, SW12, SW13, SW14, SW15, SW16, SW17, SW18, SW19, SW20: SPST; SW_PUSH_6mm

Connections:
/C1: J1.1, SW1.1 (A), SW2.1 (A), SW3.1 (A), SW4.1 (A)
/C2: J1.2, SW5.1 (A), SW6.1 (A), SW7.1 (A), SW8.1 (A)
/C3: J1.3, SW9.1 (A), SW10.1 (A), SW11.1 (A), SW12.1 (A)
/C4: J1.4, SW13.1 (A), SW14.1 (A), SW15.1 (A), SW16.1 (A)
/C5: J1.5, SW17.1 (A), SW18.1 (A), SW19.1 (A), SW20.1 (A)
/R1: J1.6, SW1.2 (B), SW5.2 (B), SW9.2 (B), SW13.2 (B), SW17.2 (B)
/R2: J1.7, SW2.2 (B), SW6.2 (B), SW10.2 (B), SW14.2 (B), SW18.2 (B)
/R3: J1.8, SW3.2 (B), SW7.2 (B), SW11.2 (B), SW15.2 (B), SW19.2 (B)
/R4: J1.9, SW4.2 (B), SW8.2 (B), SW12.2 (B), SW16.2 (B), SW20.2 (B)

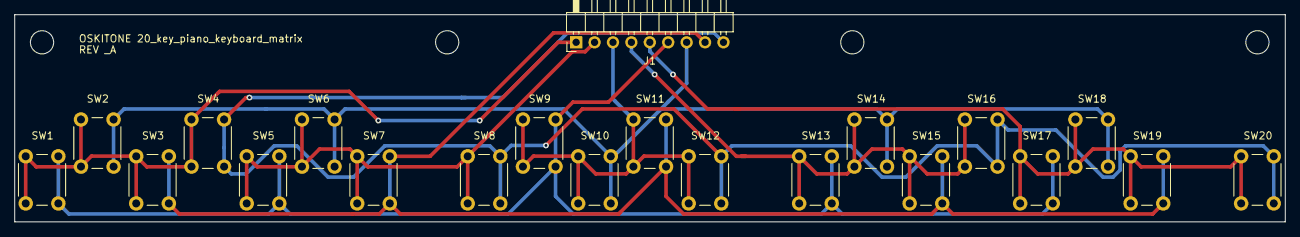
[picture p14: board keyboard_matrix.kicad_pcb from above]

Board: 2 copper layers, 175.3 x 28.6 mm, 25 parts (0 on the bottom side), 9 nets.

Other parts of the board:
 : 3.2mm; MountingHole_3.2mm_M3
 #2,  #3,  #4: 3.2mm; MountingHole_3.2mm_M3

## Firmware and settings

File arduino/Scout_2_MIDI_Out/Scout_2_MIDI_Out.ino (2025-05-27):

// SPDX-FileCopyrightText: 2025 Liz Clark
//
// SPDX-License-Identifier: MIT
/*
  Scout 2 MIDI Keyboard Controller
  * NoteOn and NoteOff messages for each key press
  * OCTAVE_PIN adjusts MIDI note number range
  * GLIDE_PIN controls pitch bend
*/

#include "Arduino.h"
#include "KeyBuffer.h"
#include "MIDI_Notes.h"

// pin defs
const int OCTAVE_PIN = A4;
const int GLIDE_PIN = A5;
const int PLAYING_INDICATOR_LED = 13;
const int FUNCTION_INDICATOR_LED = A3;

// MIDI constants
const int MIDI_CHANNEL = 1;
const int DEFAULT_VELOCITY = 64; // middle velocity

KeyBuffer buffer;
MIDI_Notes midiNotes(48); // start at C3 (MIDI note 48)

// variables
int octave = 0;
int pitchBend = 8192; // center position (no bend)
bool activeNotes[25] = {false}; // track which notes are pressed
unsigned long lastNoteTime[25] = {0}; // debounce timing for each key
const unsigned long NOTE_DEBOUNCE = 20; //

void blink(int count = 2, int timePerColor = 100) {
  while (count >= 0) {
    digitalWrite(PLAYING_INDICATOR_LED, HIGH);
    digitalWrite(FUNCTION_INDICATOR_LED, LOW);
    delay(timePerColor);
    digitalWrite(PLAYING_INDICATOR_LED, HIGH);
    digitalWrite(FUNCTION_INDICATOR_LED, HIGH);
    delay(timePerColor);
    digitalWrite(PLAYING_INDICATOR_LED, LOW);
    digitalWrite(FUNCTION_INDICATOR_LED, HIGH);
    delay(timePerColor);
    digitalWrite(PLAYING_INDICATOR_LED, LOW);
    digitalWrite(FUNCTION_INDICATOR_LED, LOW);
    delay(timePerColor);
    count = count - 1;
  }
}

void setup() {
  // MIDI baud rate:
  Serial.begin(31250);
  
  pinMode(PLAYING_INDICATOR_LED, OUTPUT);
  pinMode(FUNCTION_INDICATOR_LED, OUTPUT);

  blink();
  
  // send initial pitch bend to center position
  sendPitchBend(MIDI_CHANNEL, 8192);
}

void sendPitchBend(int channel, int bend) {
  // pitch bend uses 14-bit value split into LSB and MSB
  int lsb = bend & 0x7F;
  int msb = (bend >> 7) & 0x7F;
  
  Serial.write(0xE0 | (channel - 1)); // pitch bend message
  Serial.write(lsb);
  Serial.write(msb);
}

void sendAllNotesOff() {
  // all notes off (CC 123)
  Serial.write(0xB0 | (MIDI_CHANNEL - 1)); // CC
  Serial.write(123); // 123
  Serial.write(0);
}

void updateFromAnalogInputs() {
  int newOctave = map(analogRead(OCTAVE_PIN), 0, 1023, -2, 2); // -2 to +2 octaves
  int newPitchBend = map(analogRead(GLIDE_PIN), 0, 1023, 0, 16383); // pitch bend range
  
  if (octave != newOctave) {
    // send all notes off before changing octave, avoid stuck notes
    sendAllNotesOff();
    
    octave = newOctave;
    midiNotes.setOctaveShift(octave);
    digitalWrite(FUNCTION_INDICATOR_LED, HIGH);
  } else if (abs(pitchBend - newPitchBend) > 64) { // Add some hysteresis to reduce jitter
    pitchBend = newPitchBend;
    sendPitchBend(MIDI_CHANNEL, pitchBend);
    digitalWrite(FUNCTION_INDICATOR_LED, HIGH);
  } else {
    digitalWrite(FUNCTION_INDICATOR_LED, LOW);
  }
}

void sendNoteOn(int channel, int pitch, int velocity) {
  Serial.write(MIDI_NOTE_ON | (channel - 1));
  Serial.write(pitch);
  Serial.write(velocity);
}

void sendNoteOff(int channel, int pitch) {
  Serial.write(MIDI_NOTE_OFF | (channel - 1));
  Serial.write(pitch);
  Serial.write(0);
}

void loop() {
  // update octave and glide from analog inputs
  updateFromAnalogInputs();
  
  // update the key buffer with current key states
  buffer.populate();
  
  // update playing indicator LED
  if (buffer.isEmpty()) {
    digitalWrite(PLAYING_INDICATOR_LED, LOW);
  } else {
    digitalWrite(PLAYING_INDICATOR_LED, HIGH);
  }
  
  // scan matrix for noteon/noteoff
  for (int i = 0; i < 25; i++) {
    bool isPressed = false;
    for (int j = 0; j < buffer.getSize(); j++) {
      if (buffer.getElement(j) == i) {
        isPressed = true;
        break;
      }
    }
    // debounce
    unsigned long currentTime = millis();

    if (isPressed && !activeNotes[i]) {
      // key was just pressed
      if (currentTime - lastNoteTime[i] > NOTE_DEBOUNCE) {
        int midiNote = midiNotes.get(i);
        if (midiNote >= 0) {
          sendNoteOn(MIDI_CHANNEL, midiNote, DEFAULT_VELOCITY);
          activeNotes[i] = true;
          lastNoteTime[i] = currentTime;
        }
      }
    } else if (!isPressed && activeNotes[i]) {
      // key was just released
      if (currentTime - lastNoteTime[i] > NOTE_DEBOUNCE) {
        int midiNote = midiNotes.get(i);
        if (midiNote >= 0) {
          sendNoteOff(MIDI_CHANNEL, midiNote);
          activeNotes[i] = false;
          lastNoteTime[i] = currentTime;
        }
      }
    }
  }
}

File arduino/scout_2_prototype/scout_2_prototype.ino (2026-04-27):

#include "Frequency.h"
#include "KeyBuffer.h"
#include "NewTone.h"
#include "Notes.h"

// SETTINGS
int octave = 3;
int glide = 0;
bool glideOnFreshKeyPresses = true;
bool printToSerial = false;

const int CYCLES_PER_GLIDE_MAX = printToSerial ? 25 : 250;
const int STARTING_NOTE_DISTANCE_FROM_MIDDLE_A = -9;

const int OCTAVE_PIN = A4;
const int GLIDE_PIN = A5;

const int PLAYING_INDICATOR_LED = 13; // ie LED_BUILTIN
const int FUNCTION_INDICATOR_LED = A3;

const int INPUT_THROTTLE_MS = 100;

Notes notes(STARTING_NOTE_DISTANCE_FROM_MIDDLE_A);
KeyBuffer buffer;
Frequency frequency[OSCILLATORS_MAX] = {{glide, CYCLES_PER_GLIDE_MAX},
                                        {glide, CYCLES_PER_GLIDE_MAX},
                                        {glide, CYCLES_PER_GLIDE_MAX},
                                        {glide, CYCLES_PER_GLIDE_MAX}};

void blink(int count = 2, int timePerColor = 100) {
  while (count >= 0) {
    digitalWrite(PLAYING_INDICATOR_LED, HIGH);
    digitalWrite(FUNCTION_INDICATOR_LED, LOW);
    delay(timePerColor);
    digitalWrite(PLAYING_INDICATOR_LED, HIGH);
    digitalWrite(FUNCTION_INDICATOR_LED, HIGH);
    delay(timePerColor);
    digitalWrite(PLAYING_INDICATOR_LED, LOW);
    digitalWrite(FUNCTION_INDICATOR_LED, HIGH);
    delay(timePerColor);
    digitalWrite(PLAYING_INDICATOR_LED, LOW);
    digitalWrite(FUNCTION_INDICATOR_LED, LOW);
    delay(timePerColor);

    count = count - 1;
  }
}

void setup() {
  Serial.begin(9600);

  pinMode(PLAYING_INDICATOR_LED, OUTPUT);
  pinMode(FUNCTION_INDICATOR_LED, OUTPUT);

  newToneSetup();

  blink();
}

void updateFromAnalogInputs() {
  static uint32_t lastExecution = 0;
  uint32_t currentMillis = millis();

  if (currentMillis - lastExecution < INPUT_THROTTLE_MS) {
    return;
  }

  lastExecution = currentMillis;

  int newOctave = map(analogRead(OCTAVE_PIN), 0, 1023, -1, 4);
  int newGlide = map(analogRead(GLIDE_PIN), 0, 1023, 0, GLIDE_MAX);

  if (octave != newOctave || glide != newGlide) {
    octave = newOctave;
    glide = newGlide;

    digitalWrite(FUNCTION_INDICATOR_LED, HIGH);
  } else {
    digitalWrite(FUNCTION_INDICATOR_LED, LOW);
  }
}

void loop() {
  buffer.populate();
  uint8_t size = buffer.getSize();

  updateFromAnalogInputs();

  if (printToSerial) {
    for (uint8_t i = 0; i < size; i++) {
      frequency[i].print();
    }
  }

  if (buffer.isEmpty()) {
    digitalWrite(PLAYING_INDICATOR_LED, LOW);
  } else {
    digitalWrite(PLAYING_INDICATOR_LED, HIGH);
  }

  for (uint8_t i = 0; i < OSCILLATORS_MAX; i++) {
    if (i < size) {
      if (glide == 0 || i == 0) {
        frequency[i].update(
            notes.get(buffer.getElement(i)) / 4 * pow(2, octave), glide);
        loadTone(i, frequency[i].getHalfPeriod());
      } else {
        frequency[i].reset();
        loadTone(i, 0);
      }
    } else {
      if (!glideOnFreshKeyPresses) {
        frequency[i].reset();
      }
      loadTone(i, 0);
    }
  }
}

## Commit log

2025-03-09 Copy over relevant scout repo stuff
    Commit d72051ae, the scout_2_protoype PCB but
    no code changes
    [keyboard_matrix.kicad_pcb, keyboard_matrix.kicad_sch, keyboard_matrix.sch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]
2025-03-09 Hack Arduino code to feature ~parity
2025-03-09 Copy over parts_cafe stuff
    From branch scout_2_pcb_base commit 9b94313,
    prototype_pcb_assembly renamed scout_2_prototype
    [scout_2_prototype.scad]
2025-03-10 Elevate PCB from battery_holder more
    Turns out derived clearance wasn't enough and
    pins were shorting against batteries...
    [scout_2_prototype.scad]
2025-03-10 Support PCB in the back
    [scout_2_prototype.scad]
2025-03-10 Fillet keys on render
    [scout_2_prototype.scad]
2025-03-12 Update to latest kicad
    No changes otherwise
    [keyboard_matrix.kicad_sch, scout.kicad_sch]
2025-03-12 Update schematic
    Should be no changes to function or PCB...
    * Note pin assignments
    * Tidy RV2 and RV3 voltage dividers
    * Have MIDI read left to right
    * Specify 1N4148 diodes
    And add to readme
    [keyboard_matrix.kicad_sch, scout.kicad_sch]
2025-03-12 Update readme
    * Do some TODOs
    * Add some pics
    * Misc text cleanup
    [s2p-5e9df84-base.stl, s2p-5e9df84-battery_holder.stl, s2p-5e9df84-keys.stl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]
2025-03-12 Add final-assembly-timelapse to readme
2025-03-12 Doc BOM
    [bom.csv]
2025-03-14 Stub simple deploy script
    to avoid Arduino IDE
2025-03-14 Tidy
    * Drop some odd comments
    * Do a TODO about LEDs
    * Adopt clang formatting
2025-03-15 Note UART header orientation
2025-03-21 Replace tone() with a Timer2 ISR that toggles the for speaker I/O
    Very hacky, gets out of tune.
2025-03-21 4-note polyphony. Broken glides. Out of tune. But it's a start.
    [KeyBuffer.cpp]
2025-03-21 Reverse order of keys in buffer
    Fixes glide sorting
    [KeyBuffer.cpp]
2025-03-22 Limit octave range
    Due to timer ISR precision, the lowest pitch we can play is 122 Hz. Tuning also gets worse the higher pitch we go. Cutting off an octave at either end works around this. I would like to improve this 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
2025-03-22 Revert "Reverse order of keys in buffer"
    This reverts commit c45f9245a73179720c688cd9e9a4371b077e695c.
    [KeyBuffer.cpp]
2025-03-27 Fix a couple readme typos
2025-05-24 Fix silkscreen SVG path
    [scout_2_prototype.scad]
2025-05-24 Rotate battery holder for easier access
    [scout_2_prototype.scad]
2025-05-26 adding MIDI controller example
    Scout 2 MIDI Keyboard Controller
    * NoteOn and NoteOff messages for each key press
    * OCTAVE_PIN adjusts MIDI note number range
    * GLIDE_PIN controls pitch bend
    i tried to match the API from the Notes helper in the scout example to the MIDI_Notes helper.
2025-07-17 Rename arduino project to match repo
2026-04-01 Try to reduce noise and other refinements
    * Add decoupling cap before amp
    * Add snubber circuit after amp
    * Consider bass boost for next rev
    * Self-document pin connection assignments in schematic
    * Move branding text beyond key area
    * Reverse power switch direction
    * Enlarge UART hookup labels
    [keyboard_matrix.kicad_sch, scout.kicad_pcb, scout.kicad_sch]
2026-04-27 Reduce noise
    * Throttle updateFromAnalogInputs()
    * Fix overzealous glide updates from unnecessary
    float casting
    [scout_2_prototype.ino]

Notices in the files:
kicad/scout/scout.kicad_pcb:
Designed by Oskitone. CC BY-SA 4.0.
